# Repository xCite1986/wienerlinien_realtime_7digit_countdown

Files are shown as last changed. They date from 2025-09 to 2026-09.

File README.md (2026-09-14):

# 🚏 Wiener Linien Countdown Display

Dieses Projekt realisiert eine **4-stellige LED-Uhr mit NeoPixel 7-Segment Anzeige**, die  
über WLAN die **Echtzeit-Abfahrten der Wiener Linien (OGD-API)** abruft und als **Countdown** anzeigt.  

Neben der Anzeige verfügt das Projekt über ein **Webinterface**, flexible Konfiguration, OTA-Updates  
sowie eine **REST-API** zur Steuerung.

---

## ✨ Features

- Anzeige der Abfahrtszeit als Countdown (MM:SS)  
- Farben abhängig von verbleibender Zeit (Grün / Gelb / Rot)  
- 4-stelliges 7-Segment Display mit Doppelpunkt (58 LEDs gesamt)  
- Webinterface mit:
  - WLAN & API-Key Setup
  - Konfigurationsmöglichkeiten der LED-Farben, dessen Schwellwerte und Helligkeit
  - Standby-Modus/LED on/off
  - **Standby-Zeitplan**: Wochentage + Weckzeiten wählen, Display wacht automatisch auf und geht nach X Sekunden wieder in Standby
  - Live-Countdown + API-Log
  - OpenStreetMap-Karte der Haltestelle
- REST-API (siehe unten)  
- Konfigurationsspeicherung auf LittleFS

---

## 🛠️ Benötigte Hardware

- [Wemos D1 Mini (ESP8266)](https://www.amazon.de/dp/B06Y1ZPNMS)
- [NeoPixel-LED Streifen, 60 LEDs/m](https://www.amazon.de/dp/B09N9BJMZB) – mindestens 58 LEDs benötigt  
- 5V Netzteil (≥ 2A) – [Beispiel](https://www.amazon.de/dp/B078Q2ZMPT)  
- Kabel, evtl. Breadboard oder Lötleisten zm testen
- 3D-Drucker + Filament ;-)  

---

## 🧑‍🏫 Tutorial

### 1. Hardware Setup

1. Trägerplatte mit dem 3D-Drucker herstellen, du findest sie [auf Makerworld unter 892517](https://makerworld.com/de/models/892517-7-segment-clock-for-led-strips) 
2. NeoPixel Segmente zuschneiden und zu 4 Ziffern + Doppelpunkt zusammenfügen  
3. LEDs auf Trägerplatte kleben

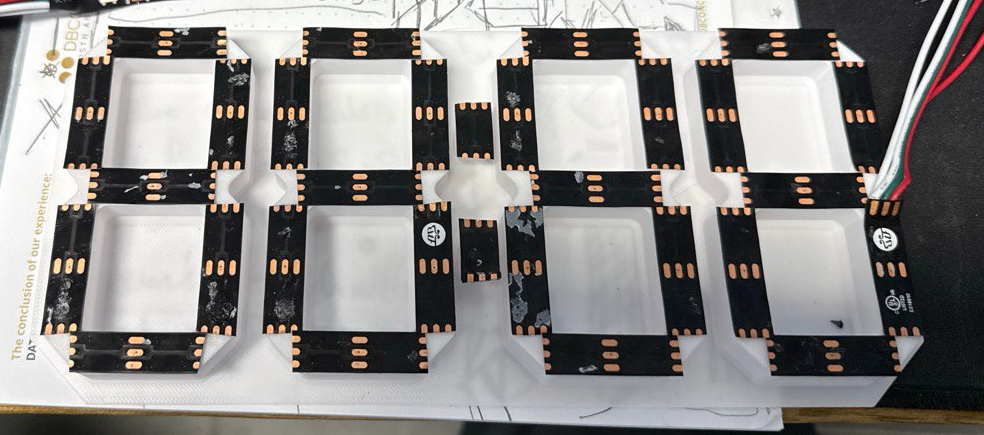
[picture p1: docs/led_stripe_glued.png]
Verklebtes LED-Stripe


5. Verdrahtung herstellen

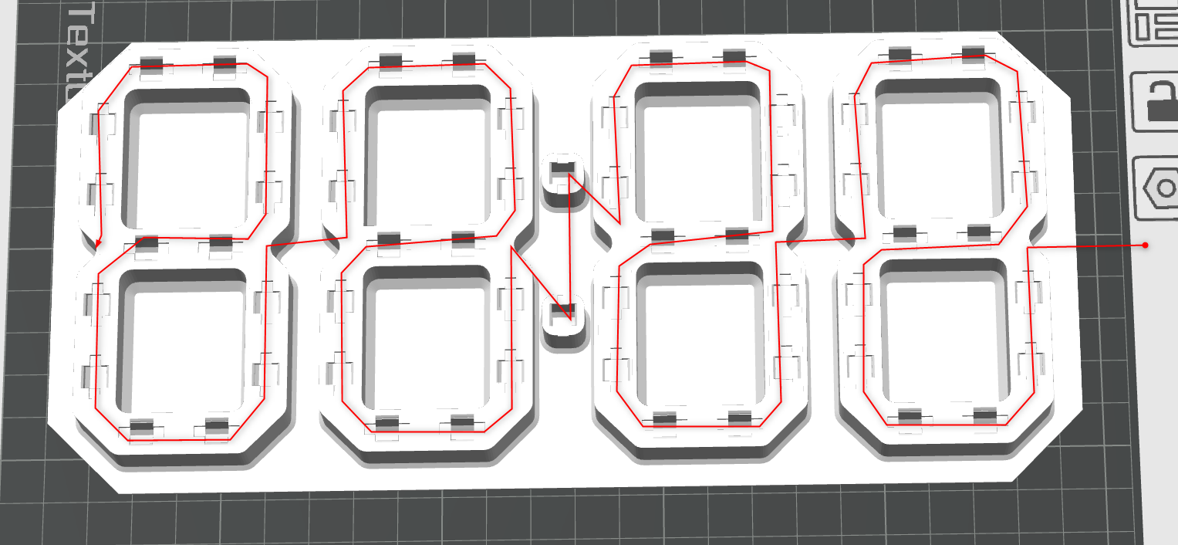
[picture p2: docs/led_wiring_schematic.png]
Schema LED-Stripe

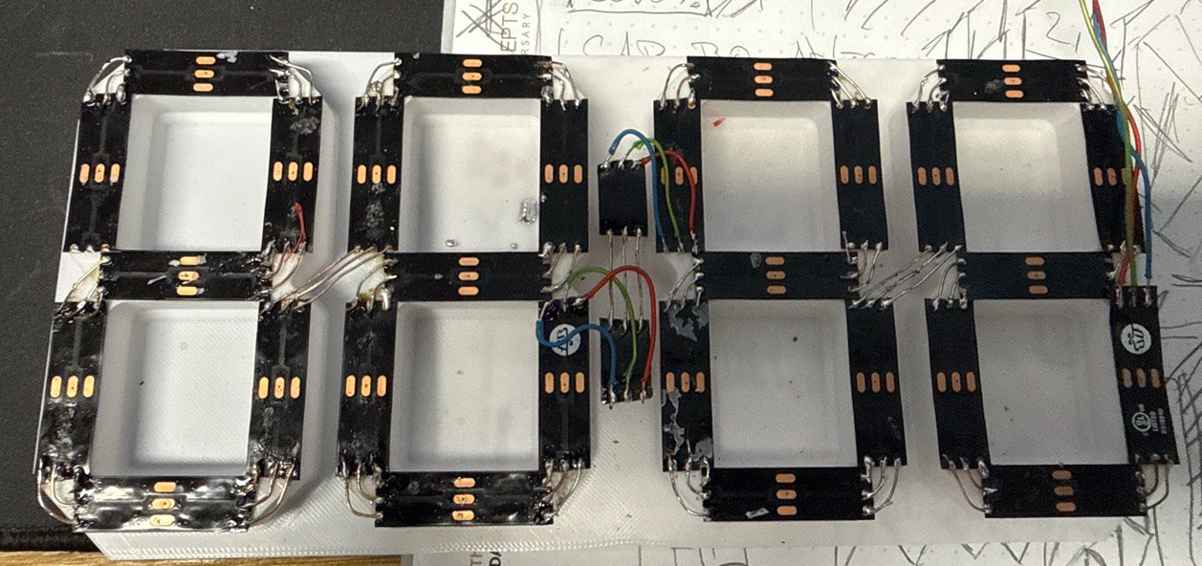
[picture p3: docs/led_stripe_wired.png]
Verdrahtetes LED-Stripe


6. Wemos D1 Mini verbinden:

   - **D2 (GPIO4)** → Data-In NeoPixel  
   - **5V** → VCC Strip  
   - **GND** → GND Strip  
   - Optional: 330 Ω Widerstand in Datenleitung  
   - Optional: 1000 µF Elko zwischen 5V und GND

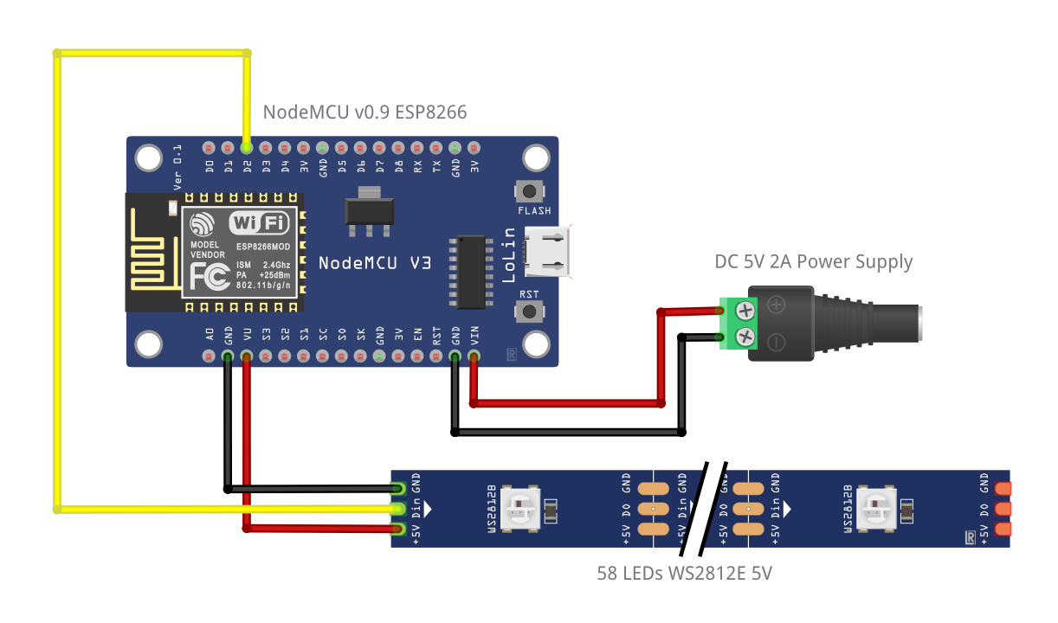
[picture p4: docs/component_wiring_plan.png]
Schematische Verdrahtung


---

### 2. Software Setup

1. **Arduino IDE installieren** → [Download](https://www.arduino.cc/en/software)  
2. ESP8266 Board Paket hinzufügen:  
   `http://arduino.esp8266.com/stable/package_esp8266com_index.json`  
3. ggf. Bibliotheken manuell installieren (bei mir wurden sie über die neue Arduino-IDE (2.3.6) selbstständig installiert):
   - `Adafruit NeoPixel`
   - `ArduinoJson`
   - `ESP8266WiFi`, `ESP8266WebServer`, `ArduinoOTA`, `ESP8266mDNS`
   - `LittleFS`

---

### 3. Erstes Testen

Zum Testen der Verdrahtung:  
- Sketch `led_check.ino` flashen  
- Alle LEDs laufen nacheinander in Rot, Grün, Blau und Weiß durch  
- So kannst du defekte oder falsch angeschlossene LEDs ausschließen

---

### 4. Firmware Flashen

- Sketch `wl7segment.ino` flashen  
- Folgende Einstellungen in der Arduino-IDE verwenden

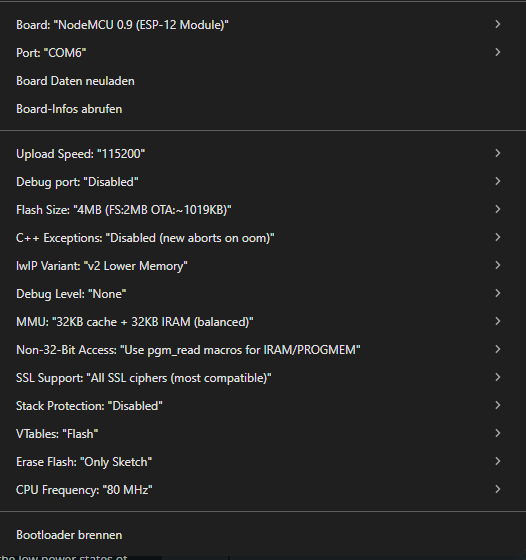
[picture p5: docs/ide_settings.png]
IDE-Settings


---

### 5. Konfiguration

Beim ersten Start:  
- ESP startet im Setup-Modus → WLAN „**WienerLinienDisplaySetup**“ verbinden  
- Passwort: `12345678`  
- Browser öffnen: [http://192.168.4.1](http://192.168.4.1/) oder [http://wldisplay.local](http://wldisplay.local)
- SSID, Passwort, RBL-Nummer (Haltestellen-ID) und API-Key der Wiener Linien eingeben  

Im normalen Betrieb:  
- Zugriff über vergebene IP oder [http://wldisplay.local](http://wldisplay.local)  

Einstellungen im Webinterface:  
- **LED-Farben & Schwellwerte** (z. B. Rot < 2min)  
- **Helligkeit** (0–255)  
- **Standby-Modus** (Display AUS, Polling pausiert)

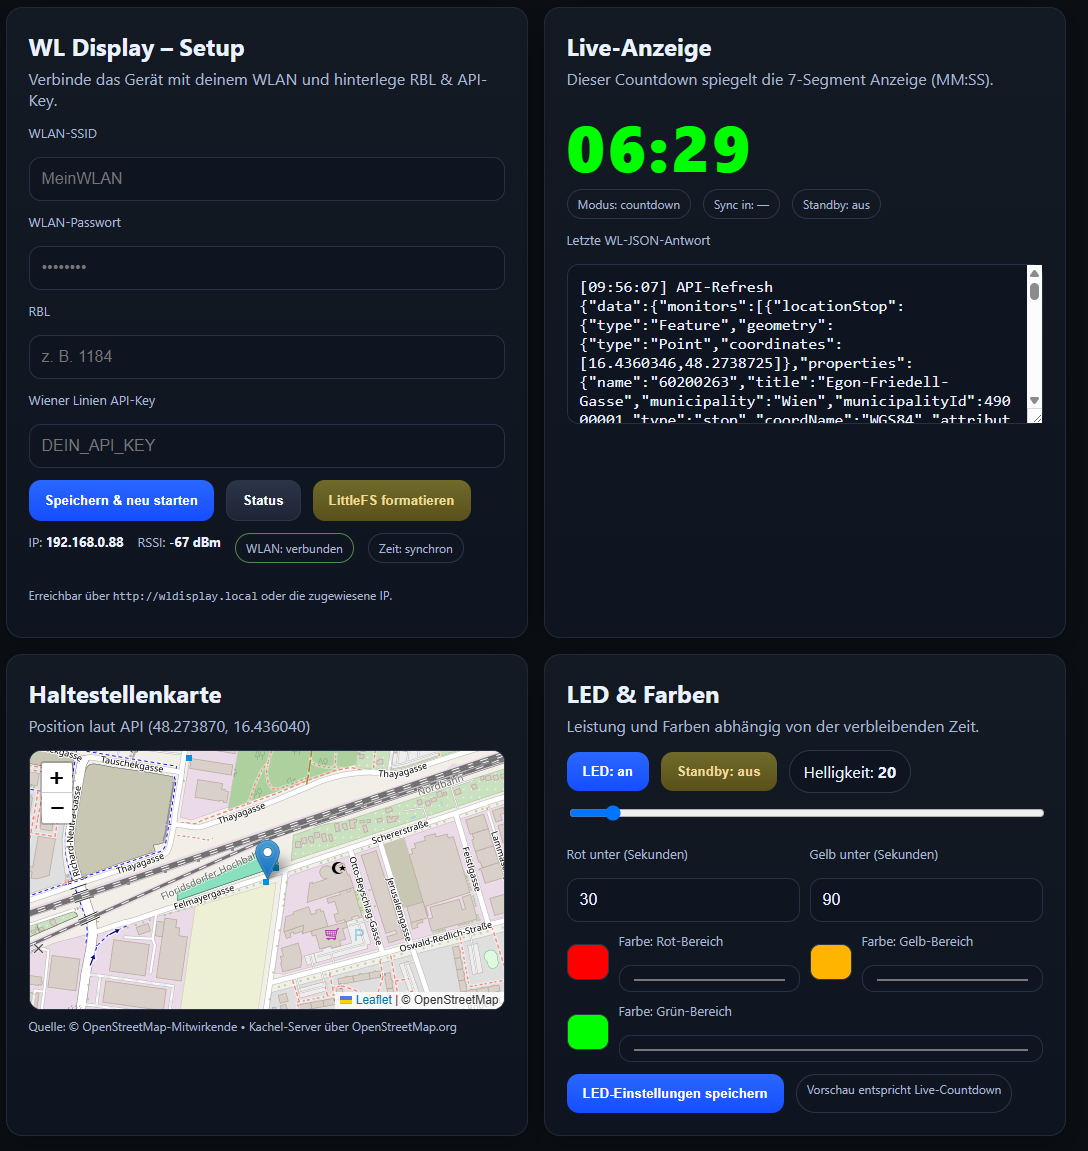
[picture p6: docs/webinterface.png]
wWebinterface


---

### 🌐 REST-API

Die Firmware bietet eine REST-Schnittstelle:

| Endpoint | Methode | Beschreibung |
|---|---|---|
| `/api/status` | GET | Status (IP, RSSI, Countdown etc.) |
| `/api/config` | POST | WLAN + API Config speichern |
| `/api/led` | POST | LED-Einstellungen (Helligkeit, Farben) |
| `/api/display` | POST | Anzeige-Modus (countdown, off, minus, standby) |
| `/api/standby` | POST | Standby ein/aus |
| `/api/schedule` | POST | Standby-Zeitplan (Wochentage, Weckzeiten, Wachdauer) |
| `/api/fetch-now` | POST | Sofort neue API-Abfrage |
| `/api/fs-format` | POST | LittleFS formatieren |
| `/api/last-payload`  | GET | Letzte Rohantwort der Wiener Linien API |

### 📡 REST-API Beispiele

Alle POST-Endpunkte erwarten **JSON** im Request-Body.  
Die Antworten kommen ebenfalls als JSON zurück.

## 🔧 /api/config  
Speichert WLAN- und API-Einstellungen im LittleFS.

```bash
curl -X POST http://wldisplay.local/api/config   -H "Content-Type: application/json"   -d '{
    "ssid": "MeinWLAN",
    "password": "WLAN_PASSWORT",
    "rbl": "1184",
    "apikey": "DEIN_API_KEY"
  }'
```

---

## 💡 /api/led  
Stellt Helligkeit und Farben ein.  
Farben im RGB-Format (`0–255`).

```bash
curl -X POST http://wldisplay.local/api/led   -H "Content-Type: application/json"   -d '{
    "brightness": 150,
    "color_green": [0,255,0],
    "color_yellow": [255,255,0],
    "color_red": [255,0,0]
  }'
```

---

## 🖥️ /api/display  
Ändert den Anzeigemodus.

Mögliche Werte:  
- `countdown` → normaler Countdown  
- `off` → Display komplett aus  
- `minus` → zeigt `--` (Fehler/kein Signal)  
- `standby` → LEDs aus, Polling pausiert  

```bash
curl -X POST http://wldisplay.local/api/display   -H "Content-Type: application/json"   -d '{"mode": "standby"}'
```

---

## 🛑 /api/standby  
Einfacher Shortcut, um Standby ein- oder auszuschalten.

```bash
curl -X POST http://wldisplay.local/api/standby   -H "Content-Type: application/json"   -d '{"enabled": true}'
```

---

## ⏰ /api/schedule  
Konfiguriert den Standby-Zeitplan. Das Gerät bleibt im Standby und wacht nur zu den
angegebenen Weckzeiten an den gewählten Wochentagen auf; `wakeSecs` Sekunden nach dem
Aufwachen kehrt es in den Standby zurück.

- `enabled`: Zeitplan aktiv (bei `true` geht das Gerät sofort in Standby)
- `days`: Bitmaske der Wochentage – `bit0=Mo, bit1=Di, … bit6=So` (z. B. `31` = Mo–Fr)
- `times`: Array von Weckzeiten als **Minuten seit Mitternacht** (max. 8; `450` = 07:30)
- `wakeSecs`: Sekunden, die das Display nach dem Aufwachen aktiv bleibt

```bash
curl -X POST http://wldisplay.local/api/schedule   -H "Content-Type: application/json"   -d '{
    "enabled": true,
    "days": 31,
    "times": [450, 720, 1020],
    "wakeSecs": 60
  }'
```

Der aktuelle Zeitplan-Status (inkl. Restwachzeit) steht auch in `/api/status` unter `schedule`.

---

## 🔄 /api/fetch-now  
Erzwingt sofort eine neue API-Abfrage.

```bash
curl -X POST http://wldisplay.local/api/fetch-now
```

---

## 🔄 /api/status  
Liefert den aktuellen Status der Anzeige.

```bash
curl http://wldisplay.local/api/status
```

JSON-Antwort:
```
{
  "ip": "192.168.0.88",
  "rssi": -60,
  "lastDisplay": "00:31",
  "secondsToBus": 0,
  "lastUpdateMs": 24657563,
  "timeSynced": true,
  "now": 1759390697,
  "standby": true,
  "ledPower": true,
  "brightness": 20,
  "currentColor": [255, 180, 0],
  "thresholds": {
    "low": 30,
    "mid": 90
  },
  "colors": {
    "low": [255, 0, 0],
    "mid": [255, 180, 0],
    "high": [0, 255, 0]
  },
  "coords": {
    "lat": 48.27387,
    "lon": 16.43604
  },
  "mode": "standby",
  "ssid": "49er_5G",
  "apiKey": "xxxxxxxxx",
  "rbl": "1184",
  "httpsInsecure": false,
  "httpsFingerprint": "",
  "loglen": 6000
}
```

---

### 📸 Fertige Anzeige:  

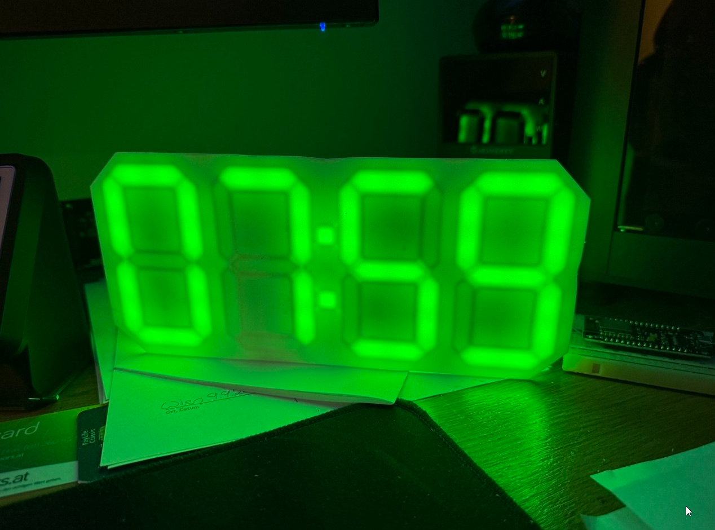
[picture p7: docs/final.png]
Final


---

### ✅ Zusammenfassung

- LEDs verkabeln  
- Mit `led_check.ino` testen  
- Mit `wl_7_segment.ino` + LittleFS flashen  
- Im Setup-WLAN konfigurieren  
- Countdown genießen 🚏

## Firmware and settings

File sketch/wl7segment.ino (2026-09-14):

/*
  Wiener Linien Countdown + NeoPixel 7-Segment mit REST-API + OSM-Karte
  - Setup/Status-Webseite
  - Live-Countdown (MM:SS) farbig wie LEDs
  - LED-Steuerung (Power, Helligkeit, Farben, Schwellwerte), Standby
  - LittleFS formatieren (Button)
  - Countdown nur aus timeReal vs serverTime (kein API-countdown)
  - Robuste String-Suche (timeReal, serverTime, coordinates)
  - HTTPS via BearSSL (optional Fingerprint, sonst insecure)
  - OTA + mDNS, LittleFS
*/

#include <ESP8266WiFi.h>
#include <ESP8266WebServer.h>
#include <ESP8266HTTPClient.h>
#include <WiFiClientSecureBearSSL.h>
#include <ESP8266mDNS.h>
#include <ArduinoOTA.h>
#include <Adafruit_NeoPixel.h>
#include <LittleFS.h>
#include <ArduinoJson.h>
#include <time.h>

// ---------- Hardware ----------
#define LED_PIN         D2
#define NUM_DIGITS      4
#define NUM_SEGMENTS    7
#define LEDS_PER_SEG    2
#define NUM_LEDS        58

// ---------- LED Strip ----------
Adafruit_NeoPixel strip(NUM_LEDS, LED_PIN, NEO_GRB + NEO_KHZ800);

// ---------- Web ----------
ESP8266WebServer server(80);

// ---------- Konfiguration/Status ----------
struct AppConfig {
  String ssid = "";
  String password = "";
  String apiKey = "";
  String rbl = "";
  // LED Basis
  uint8_t brightness = 40;
  bool ledPower = true;
  // Farbe & Schwellen (Sekunden)
  uint16_t tLow = 30;
  uint16_t tMid = 90;
  uint8_t  colLow[3]  = {255, 0,   0};
  uint8_t  colMid[3]  = {255, 180, 0};
  uint8_t  colHigh[3] = {0,   255, 0};
  // HTTPS
  bool httpsInsecure = false;
  String httpsFingerprint = "";
  // nur für NTP-Stempel (ohne TZ-Config, WL serverTime maßgeblich)
  String tz = "CET-1CEST,M3.5.0,M10.5.0/3";
  // Fahrplan-Fallback: timePlanned nutzen, wenn kein timeReal (Echtzeit) vorliegt
  bool allowPlannedFallback = true;
  // ----- Standby-Zeitplan -----
  bool     schedEnabled  = false;      // Zeitplan aktiv?
  uint8_t  schedDays     = 0;          // Bitmaske: bit0=Mo, bit1=Di, ... bit6=So
  uint32_t schedWakeSecs = 60;         // Sekunden wach nach dem Aufwecken
  uint16_t schedTimes[8] = {0};        // Weckzeiten als Minuten seit Mitternacht (0..1439)
  uint8_t  schedTimeCount = 0;         // Anzahl belegter Weckzeiten
} cfg;

String lastDisplayValue = "----";
String ringLog;
String lastPayload;
unsigned long lastUpdateMs = 0;
int secondsToBus = 0;
bool blinkState = false;

unsigned long nextPollAt = 0;
unsigned long nextTickAt = 0;
unsigned long backoffMs = 20000;

bool timeSynced = false;
bool standby = false;
bool usingPlanned = false; // true, wenn aktueller Countdown aus timePlanned (Fahrplan) statt timeReal stammt

// Standby-Zeitplan (Laufzeit)
unsigned long schedWakeUntil = 0;  // millis, bis wann durch Zeitplan wach
bool schedAwake = false;           // true, wenn aktuell durch Zeitplan geweckt
int  schedLastTriggerKey = -1;     // (wday*1440+minute) der letzten Auslösung → Dedup pro Minute

bool fsMounted = false;

// Robustes HTTP-GET, das JSON als String zurückliefert (ohne Chunk-/Gzip-Überraschungen)
bool httpGetJson(const String& url,
                 String& bodyOut,
                 int& httpCodeOut,
                 BearSSL::WiFiClientSecure& tlsClient,
                 uint32_t connTimeoutMs = 8000,
                 uint32_t readTimeoutMs = 8000)
{
  HTTPClient http;
  http.setTimeout(connTimeoutMs);
  http.setReuse(false);
  http.useHTTP10(true); // vermeidet Transfer-Encoding: chunked
  http.setFollowRedirects(HTTPC_STRICT_FOLLOW_REDIRECTS);
  http.addHeader("Accept", "application/json");
  http.addHeader("Accept-Encoding", "identity"); // kein gzip/deflate
  http.addHeader("Connection", "close");

  if (!http.begin(tlsClient, url)) {
    httpCodeOut = 0;
    return false;
  }

  httpCodeOut = http.GET();

  // Wenn kein 200 → aufräumen und raus
  if (httpCodeOut != HTTP_CODE_OK) {
    http.end();
    return false;
  }

  // Versuche Content-Length zu bekommen
  int len = http.getSize();
  WiFiClient *stream = http.getStreamPtr();
  bodyOut = "";
  bodyOut.reserve(len > 0 && len < 32768 ? (size_t)len : 4096);

  uint32_t start = millis();
  const uint32_t readDeadline = millis() + readTimeoutMs;

  if (len > 0) {
    // Content-Length bekannt → genau so viele Bytes lesen
    while (bodyOut.length() < (size_t)len) {
      while (stream->available()) {
        char c = (char)stream->read();
        bodyOut += c;
      }
      if (millis() > readDeadline) break;
      delay(1);
      yield();
    }
  } else {
    // Keine Länge (oder chunked/Server schließt) → bis Verbindung zu/Timeout
    while (millis() <= readDeadline && (stream->connected() || stream->available())) {
      while (stream->available()) {
        char c = (char)stream->read();
        bodyOut += c;
      }
      delay(1);
      yield();
    }
  }

  http.end();

  // Body noch leer? → als Fehler behandeln
  if (bodyOut.length() == 0) {
    return false;
  }
  return true;
}


// Halte die zuletzt gefundenen Stop-Koordinaten (GeoJSON: lon,lat)
bool haveCoords = false;
double stopLon = 0.0, stopLat = 0.0;

const time_t TIME_VALID_EPOCH = 1700000000; // ~2023-11-14

// ---------- 7-Segment Mapping (angepasst an deine Verdrahtung) ----------
// Logische Reihenfolge im Code: digit 0..3 = links→rechts  (MM:SS)
// Physische Verdrahtung (0-basiert): 44–57 (digit0), 30–43 (digit1), 14–27 (digit2), 0–13 (digit3)
// Colon sitzt dazwischen auf 28,29.

const uint8_t DIGIT_BASE[4] = {
  44, // digit 0 (links außen)  -> LEDs 45..58 (1-basiert)
  30, // digit 1 (2. von links) -> LEDs 31..44
  14, // digit 2 (3. von links) -> LEDs 15..28
   0  // digit 3 (rechts außen) -> LEDs  1..14
};

// Reihenfolge der 7 Segmente innerhalb einer Ziffer.
// Wenn deine beiden LEDs je Segment nicht genau in A,B,C,D,E,F,G laufen,
// kannst du hier einfach die Paar-Indizes (0..13) umsortieren.
// Standard: A,B,C,D,E,F,G  -> (0..13 paarweise)
const uint8_t SEG_PAIR_ORDER[7][2] = {
  {2,3},   // A  (oben)
  {0,1},   // B  (oben rechts)
  {8,9},   // C  (unten rechts)
  {10,11},   // D  (unten)
  {12,13},   // E  (unten links)
  {4,5}, // F  (oben links)
  {6,7}  // G  (Mitte)
};

// Aus obigen Tabellen das vollständige Mapping (14 Indizes pro Digit) bauen:
uint8_t digitSegmentMap[4][14];
void buildDigitMap() {
  for (uint8_t d = 0; d < 4; ++d) {
    for (uint8_t s = 0; s < 7; ++s) {
      digitSegmentMap[d][s*2+0] = DIGIT_BASE[d] + SEG_PAIR_ORDER[s][0];
      digitSegmentMap[d][s*2+1] = DIGIT_BASE[d] + SEG_PAIR_ORDER[s][1];
    }
  }
}

// 0/1-Muster für Ziffern 0..9 (A..G)
const uint8_t digitPatterns[10][7] PROGMEM = {
  {1,1,1,1,1,1,0}, {0,1,1,0,0,0,0}, {1,1,0,1,1,0,1}, {1,1,1,1,0,0,1},
  {0,1,1,0,0,1,1}, {1,0,1,1,0,1,1}, {1,0,1,1,1,1,1}, {1,1,1,0,0,0,0},
  {1,1,1,1,1,1,1}, {1,1,1,1,0,1,1}
};

// Doppelpunkt-LEDs (0-basiert):
const uint8_t COLON_IDX[2] = {28, 29};


// ---------- HTML ----------
const char INDEX_HTML[] PROGMEM = R"HTML(
<!doctype html><html lang="de"><head>
<meta charset="utf-8"><meta name="viewport" content="width=device-width,initial-scale=1,viewport-fit=cover">
<title>WL Display</title>
<link rel="preconnect" href="https://unpkg.com" />
<link rel="stylesheet" href="https://unpkg.com/leaflet@1.9.4/dist/leaflet.css">
<style>
:root{--bg:#0b0f14;--card:#121821;--ink:#eaf2ff;--dim:#a9b7cf;--accent:#3aa6ff;--ok:#7ad96b;--warn:#f5c06a}
*{box-sizing:border-box}body{margin:0;background:var(--bg);color:var(--ink);font-family:system-ui,Segoe UI,Roboto,Helvetica,Arial,sans-serif}
.wrap{max-width:1100px;margin:0 auto;padding:20px}
.grid{display:grid;gap:16px}
@media(min-width:900px){.grid-2{grid-template-columns:1fr 1fr}}
.card{background:linear-gradient(180deg,#131a24,#0f1520);border:1px solid #1f2a38;border-radius:16px;padding:clamp(14px,2.5vw,22px);box-shadow:0 10px 30px rgba(0,0,0,.35)}
h1{margin:0 0 6px;font-size:clamp(18px,4.5vw,24px)} p.lead{margin:0 0 14px;color:var(--dim)}
label{font-size:13px;color:var(--dim);display:block;margin-bottom:6px}
input,textarea,select{width:100%;padding:12px;border-radius:12px;border:1px solid #253245;background:#0e1420;color:#eaf2ff;font-size:16px}
input[type=range]{padding:0;height:36px}
textarea{min-height:160px;resize:vertical;font-family:ui-monospace,SFMono-Regular,Menlo,Consolas,monospace}
input:focus,textarea:focus{outline:none;border-color:var(--accent);box-shadow:0 0 0 4px rgba(58,166,255,.15)}
.row{display:grid;gap:10px}
.row-2{display:grid;gap:10px;grid-template-columns:1fr 1fr}
.btn{display:inline-flex;align-items:center;justify-content:center;background:linear-gradient(180deg,#2a67ff,#154eff);color:#fff;border:none;
     padding:12px 16px;border-radius:12px;font-weight:600;cursor:pointer}
.btn.secondary{background:linear-gradient(180deg,#2b3548,#1d2535);border:1px solid #2a3648}
.btn.warn{background:linear-gradient(180deg,#6f6b2a,#5a501b)}
.kv{display:flex;gap:14px;flex-wrap:wrap;color:var(--dim);font-size:13px}
.kv b{color:var(--ink)} .count{font-weight:800;font-size:clamp(36px,12vw,64px);letter-spacing:.04em}
.badge{display:inline-block;border-radius:999px;padding:6px 10px;font-size:12px;border:1px solid #2a3648;color:var(--dim)}
.flex{display:flex;gap:12px;flex-wrap:wrap}
.toast{position:fixed;left:12px;right:12px;bottom:12px;padding:14px;border-radius:12px;background:#132a17;color:#d5ffd0;border:1px solid #265c2c;display:none}
.toast.err{background:#3a1114;color:#ffd7db;border-color:#7d262c}
.small{font-size:12px;color:var(--dim)}
.warn{border-color:#6a5b2a;color:#f1da9a}
.pill{padding:10px 14px;border-radius:999px;border:1px solid #2a3648;background:#0e1420}
#stopMap{height:260px;border-radius:12px;border:1px solid #2a3648;overflow:hidden}
.map-hint{margin-top:8px;color:var(--dim);font-size:12px}
.color-row{display:flex;gap:10px;align-items:center}
.color-chip{width:42px;height:36px;border-radius:10px;border:1px solid #2a3648}
.color-wrap{display:grid;grid-template-columns:auto 1fr;gap:10px;align-items:center}
.dots{display:flex;gap:10px;flex-wrap:wrap}
.dot{display:flex;align-items:center;gap:8px;cursor:pointer;padding:8px 12px;border:1px solid #2a3648;border-radius:999px;background:#0e1420;color:var(--dim);user-select:none}
.dot input{appearance:none;-webkit-appearance:none;width:16px;height:16px;min-width:16px;padding:0;border-radius:50%;border:2px solid #3a4a63;margin:0;position:relative;background:#0e1420;box-shadow:none}
.dot input:focus{outline:none;box-shadow:0 0 0 3px rgba(58,166,255,.2)}
.dot input:checked{border-color:var(--accent)}
.dot input:checked::after{content:"";position:absolute;top:2px;left:2px;right:2px;bottom:2px;border-radius:50%;background:var(--accent)}
.dot input:checked ~ span{color:var(--ink)}
.chips{display:flex;gap:8px;flex-wrap:wrap}
.chip{display:inline-flex;align-items:center;gap:8px;padding:8px 12px;border-radius:999px;border:1px solid #2a3648;background:#0e1420;color:var(--ink);font-variant-numeric:tabular-nums}
.chip button{background:none;border:none;color:var(--dim);cursor:pointer;font-size:18px;line-height:1;padding:0;width:auto}
.chip button:hover{color:#ff8a8a}
.addrow{display:grid;grid-template-columns:1fr auto;gap:10px;align-items:end}
</style></head><body>
<div class="wrap grid grid-2">
  <div class="card">
    <h1>WL Display – Setup</h1>
    <p class="lead">Verbinde das Gerät mit deinem WLAN und hinterlege RBL & API-Key.</p>
    <div class="grid" style="gap:12px">
      <div class="row"><label for="ssid">WLAN-SSID</label><input id="ssid" placeholder="MeinWLAN"></div>
      <div class="row"><label for="pwd">WLAN-Passwort</label><input id="pwd" type="password" placeholder="••••••••"></div>
      <div class="row"><label for="rbl">RBL</label><input id="rbl" inputmode="numeric" placeholder="z. B. 1184"></div>
      <div class="row"><label for="apikey">Wiener Linien API-Key</label><input id="apikey" placeholder="DEIN_API_KEY"></div>
      <div class="flex">
        <button class="btn" id="saveBtn">Speichern & neu starten</button>
        <button class="btn secondary" id="statusBtn">Status</button>
      </div>
      <div class="kv"><span>IP: <b id="ip">-</b></span><span>RSSI: <b id="rssi">-</b></span>
        <span class="badge" id="wlstate">WLAN: unbekannt</span>
        <span class="badge warn" id="timesync">Zeit: unbekannt</span></div>
      <p class="small">Erreichbar über <code>http://wldisplay.local</code> oder die zugewiesene IP.</p>
    </div>
  </div>

  <div class="card">
    <h1>Live-Anzeige</h1>
    <p class="lead">Dieser Countdown spiegelt die 7-Segment Anzeige (MM:SS).</p>
    <div class="count" id="countMMSS" style="color:#eaf2ff">--:--</div>
    <div class="flex">
      <span class="badge" id="modeBadge">Modus: countdown</span>
      <span class="badge" id="srcBadge">Quelle: –</span>
      <span class="badge" id="nextSync">Sync in: -</span>
      <span class="badge" id="standbyBadge">Standby: aus</span>
    </div>
    <label class="pill" style="display:flex;align-items:center;gap:10px;cursor:pointer;margin-top:12px">
      <input type="checkbox" id="plannedFallback" style="width:auto;height:auto">
      <span>Fahrplan-Fallback (timePlanned), wenn keine Echtzeit — Doppelpunkt dann <b style="color:#3a86ff">blau</b></span>
    </label>
    <div class="row" style="margin-top:12px">
      <label for="log">Letzte WL-JSON-Antwort</label>
      <textarea id="log" readonly placeholder="Noch keine Daten …"></textarea>
    </div>
  </div>

  <div class="card">
    <h1>Haltestellenkarte</h1>
    <p class="lead">Position laut API (<span id="coordLbl">–</span>)</p>
    <div id="stopMap"></div>
    <div class="map-hint">Quelle: © OpenStreetMap-Mitwirkende • Kachel-Server über OpenStreetMap.org</div>
  </div>

  <div class="card">
    <h1>LED & Farben</h1>
    <p class="lead">Leistung und Farben abhängig von der verbleibenden Zeit.</p>
    <div class="flex" style="align-items:center;flex-wrap:wrap">
      <button class="btn" id="powerBtn">LED: an</button>
      <button class="btn warn" id="standbyBtn">Standby: aus</button>
      <div class="pill">Helligkeit: <b id="brightVal">0</b></div>
    </div>
    <input id="brightRange" type="range" min="0" max="255" step="1" value="40" />
    <div class="row-2" style="margin-top:10px">
      <div class="row">
        <label>Rot unter (Sekunden)</label>
        <input id="tLow" type="number" min="0" max="3600" step="1" placeholder="30">
      </div>
      <div class="row">
        <label>Gelb unter (Sekunden)</label>
        <input id="tMid" type="number" min="0" max="3600" step="1" placeholder="90">
      </div>
    </div>

    <div class="row-2" style="margin-top:10px">
      <div class="color-wrap">
        <div class="color-chip" id="chipLow"></div>
        <div class="row">
          <label>Farbe: Rot-Bereich</label>
          <input id="cLow" type="color" value="#ff0000">
        </div>
      </div>

      <div class="color-wrap">
        <div class="color-chip" id="chipMid"></div>
        <div class="row">
          <label>Farbe: Gelb-Bereich</label>
          <input id="cMid" type="color" value="#ffb400">
        </div>
      </div>
    </div>

    <div class="color-wrap" style="margin-top:10px">
      <div class="color-chip" id="chipHigh"></div>
      <div class="row" style="margin:0">
        <label>Farbe: Grün-Bereich</label>
        <input id="cHigh" type="color" value="#00ff00">
      </div>
    </div>

    <div class="flex" style="margin-top:12px">
      <button class="btn" id="ledSave">LED-Einstellungen speichern</button>
      <span class="badge" id="previewInfo">Vorschau entspricht Live-Countdown</span>
    </div>
  </div>

  <div class="card">
    <h1>Standby-Zeitplan</h1>
    <p class="lead">Das Display bleibt im Standby und wacht nur zu festgelegten Zeiten auf. Einige Sekunden nach dem Aufwachen geht es wieder schlafen.</p>

    <div class="flex" style="align-items:center;margin-bottom:14px">
      <button class="btn warn" id="schedToggle">Zeitplan: aus</button>
      <span class="badge" id="schedState">Zeitplan: aus</span>
    </div>

    <label>Wochentage</label>
    <div class="dots" id="schedDays" style="margin-bottom:14px">
      <label class="dot"><input type="checkbox" data-day="0"><span>Mo</span></label>
      <label class="dot"><input type="checkbox" data-day="1"><span>Di</span></label>
      <label class="dot"><input type="checkbox" data-day="2"><span>Mi</span></label>
      <label class="dot"><input type="checkbox" data-day="3"><span>Do</span></label>
      <label class="dot"><input type="checkbox" data-day="4"><span>Fr</span></label>
      <label class="dot"><input type="checkbox" data-day="5"><span>Sa</span></label>
      <label class="dot"><input type="checkbox" data-day="6"><span>So</span></label>
    </div>

    <label>Weckzeiten (max. 8)</label>
    <div class="addrow">
      <input id="schedTimeInput" type="time" value="07:30">
      <button class="btn secondary" id="schedAddTime">+ Zeit</button>
    </div>
    <div class="chips" id="schedTimes" style="margin-top:10px"></div>

    <div class="row" style="margin-top:14px">
      <label for="schedWakeSecs">Wach-Dauer nach dem Aufwecken (Sekunden)</label>
      <input id="schedWakeSecs" type="number" min="1" max="86400" step="1" placeholder="60">
    </div>

    <div class="flex" style="margin-top:14px">
      <button class="btn" id="schedSave">Zeitplan speichern</button>
    </div>
  </div>
</div>

<div class="toast" id="toast"></div>
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
void loop(){
  server.handleClient();
  ArduinoOTA.handle();

  // ---- Standby-Zeitplan ----
  if(cfg.schedEnabled){
    // Für den Zeitplan wird die Uhrzeit benötigt – im Standby regelmäßig nachsynchronisieren
    static unsigned long nextTimeCheck = 0;
    if(!timeSynced && millis() >= nextTimeCheck){
      nextTimeCheck = millis() + 30000;
      ensureWifi();
      ensureTime();
    }

    time_t now = time(nullptr);
    if(timeSynced && now >= TIME_VALID_EPOCH){
      struct tm lt; localtime_r(&now, &lt);
      int wd = (lt.tm_wday + 6) % 7;              // Mo=0 ... So=6
      int minOfDay = lt.tm_hour * 60 + lt.tm_min;
      int curKey = wd * 1440 + minOfDay;

      // Re-Arm: sobald wir die ausgelöste Minute verlassen, erneut scharf schalten
      if(schedLastTriggerKey != -1 && schedLastTriggerKey != curKey) schedLastTriggerKey = -1;

      // Aufwecken (flankengesteuert: pro Minute nur einmal)
      if(cfg.schedDays & (1 << wd)){
        for(uint8_t i=0; i<cfg.schedTimeCount; i++){
          if((int)cfg.schedTimes[i] == minOfDay){
            if(schedLastTriggerKey != curKey){
              schedLastTriggerKey = curKey;
              schedAwake = true;
              schedWakeUntil = millis() + (unsigned long)cfg.schedWakeSecs * 1000UL;
              standby = false;
              if(mode == DisplayMode::STANDBY) mode = DisplayMode::COUNTDOWN;
              nextPollAt = millis();  // sofort neue Daten holen
              char hhmm[6]; sprintf(hhmm, "%02d:%02d", lt.tm_hour, lt.tm_min);
              logLine(String("Zeitplan: Aufgeweckt um ") + hhmm + " für " + String(cfg.schedWakeSecs) + "s");
            }
            break;
          }
        }
      }

      // Wieder schlafen legen
      if(schedAwake && millis() >= schedWakeUntil){
        schedAwake = false;
        standby = true;
        mode = DisplayMode::STANDBY;
        displayClear();
        logLine("Zeitplan: Wachzeit abgelaufen → Standby");
      }
    }
  }

  // 1s LED/Anzeige tick
  if(millis() >= nextTickAt){
    nextTickAt += 1000;
    if(cfg.ledPower && !standby){
      uint8_t r,g,b; pickColorForSeconds(secondsToBus, r,g,b);
      if(mode==DisplayMode::COUNTDOWN){
        if(secondsToBus>0){ secondsToBus--; displayDigitsMMSS(secondsToBus,r,g,b); }
        else { blinkState=!blinkState; displayBlinkMinus(blinkState,r,g,b); }
      } else if(mode==DisplayMode::MINUS){
        blinkState=!blinkState; displayBlinkMinus(blinkState,r,g,b);
      } else displayClear();
    } else displayClear();
  }

  // Poll WL (Erfolg 20s, Fehler 5s)
  if(!standby && millis() >= nextPollAt){
    int s = fetchBusCountdown();
    if (s >= 0) { secondsToBus = s; backoffMs = 20000; }
    else { backoffMs = 5000; }
    nextPollAt = millis() + backoffMs;

    int mm = secondsToBus/60, ss = secondsToBus%60; char mmss[6]; sprintf(mmss,"%02d:%02d",mm,ss);
    Serial.println("Next poll in " + String(backoffMs) + " ms; seconds=" + String(secondsToBus) + " (" + String(mmss) + ")");
  }

  yield();
}

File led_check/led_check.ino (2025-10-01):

#include <Adafruit_NeoPixel.h>

#define PIN            D4          // D4 = GPIO2 auf dem Wemos D1 Pro/Mini
#define NUMPIXELS      58          // Anzahl der NeoPixel

Adafruit_NeoPixel pixels = Adafruit_NeoPixel(NUMPIXELS, PIN, NEO_GRB + NEO_KHZ800);

void setup() {
  pixels.begin(); // Initialisierung der NeoPixel
  pixels.clear(); // Alle Pixel aus
  pixels.show();
}

void loop() {
  // Test 1: Alle nacheinander rot, grün, blau durchgehen
  for (uint16_t i=0; i<NUMPIXELS; i++) {
    pixels.setPixelColor(i, pixels.Color(255,0,0)); // Rot
    pixels.show();
    delay(50);
  }
  delay(300);
  for (uint16_t i=0; i<NUMPIXELS; i++) {
    pixels.setPixelColor(i, pixels.Color(0,255,0)); // Grün
    pixels.show();
    delay(50);
  }
  delay(300);
  for (uint16_t i=0; i<NUMPIXELS; i++) {
    pixels.setPixelColor(i, pixels.Color(0,0,255)); // Blau
    pixels.show();
    delay(50);
  }
  delay(300);

  // Test 2: Alle gleichzeitig weiß
  for (uint16_t i=0; i<NUMPIXELS; i++) {
    pixels.setPixelColor(i, pixels.Color(255,255,255));
  }
  pixels.show();
  delay(1000);

  // Ausmachen
  pixels.clear();
  pixels.show();
  delay(1000);
}

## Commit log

2025-09-29 add some functions and code corrections
    - Mobil-optimierte Setup-/Status-Seite auf /
    * Formular (SSID/Passwort/RBL/API-Key)
    * Live-Countdown (MM:SS) – ident zur 7-Segment Anzeige
    * Logfenster mit letzter WL-JSON-Antwort
    * LED-Steuerung: Power, Brightness, 3 Farben + 2 Schwellwerte
    - Countdown-Berechnung NUR: time(dep) - time(now) (niemals API 'countdown')
    - Robust: ArduinoJson-Filter + String-Fallback mit korrekter TZ (+hhmm/Z)
    - NTP-Racefix (timeSynced): es wird erst nach Zeit-Sync gerechnet
    - Serial-Logs inkl. Sekunden & MM:SS
    - HTTPS: Fingerprint optional; sonst setInsecure()
    - OTA + mDNS, LittleFS
2025-10-01 add led check ino
2025-10-02 pictures and documentation
    [led_clock_fritzing.fzz]
2026-07-21 Add planned timetable fallback support
    Add support for using planned departure times (Fahrplan) as fallback when real-time data (timeReal) is unavailable. Includes:
    - New `allowPlannedFallback` config option to enable/disable the feature
    - Visual indicators: source badge shows 'Echtzeit' or 'Fahrplan', colon turns blue when using planned data
    - New `/api/behavior` endpoint to toggle fallback without restart
    - Setup form auto-prefill from current config
    - Updated logic in fetchBusCountdown() to try real-time first, then planned if enabled
    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
2026-09-14 Fix ESP8266-Absturz beim Speichern/Umschalten des Zeitplans
    Ursache war ein Stack-Ueberlauf: StaticJsonDocument liegt komplett auf
    dem knappen ~4KB cont-Stack des ESP8266. Die (fuer den Zeitplan
    vergroesserten) Dokumente in den Web-Handlern und im Save-Pfad haben den
    Stack gesprengt - besonders wenn /api/status bei offener Weboberflaeche
    im Sekundentakt gepollt wird und ein Save oben drauf kommt.
    - Alle StaticJsonDocument -> DynamicJsonDocument (Heap statt Stack)
    - Diagnose in /api/status: freeHeap + freeStack
    Verifiziert am Geraet: 14 schnelle Save/Toggle-Zyklen ohne Reboot
    (loglen waechst monoton), freeStack stabil ~1KB frei, kein Heap-Leak.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
    [wl7segment.ino]
